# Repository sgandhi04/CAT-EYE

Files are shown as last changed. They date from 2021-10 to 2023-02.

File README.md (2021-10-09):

# CAT-EYE
New social distancing guidelines imposed during COVID-19 have made it extremely difficult for the bind to maintain their independence. The World Health Organization (WHO) estimates that 88% of the world's blind population is 50 years and older, making this demographic extremely vulnerable to COVID-19. Despite this alarming statistic, little  has been done to help the visually impaired cope with this pandemic. The CAT-EYE, a low- cost wearable assistive technology in the form of a hat, solves this problem by assisting  blind individuals with navigating in a pandemic-stricken world. The CAT-EYE consists of three systems that work together to inform a blind user about their surroundings: 1. Mask Detection: When individuals come within six-feet of the user, CAT-EYE detects their presence using a LIDAR sensor and communicates their general location through vibrotactile motors. 2. Proximity Sensing: When individuals within six feet of the user are not wearing a mask, the device beeps loudly. This system was built using computer vision for the first prototype and AI, 3. IoT, and the NVIDIA Jetson Nano for the second prototype. 3. Public Alert: The user has the option to broadcast an alert through a speaker on the hat. This alert will notify people in the user's surroundings about the presence of a blind individual. The CAT-EYE was tested by analyzing performance in the camera's field of vision from 90 to 135 degrees. Design iterations based on test results helped CAT-EYE achieve 87% accuracy. The results demonstrated the applicability of the proposed solution as a pandemic-navigation aid to the blind.

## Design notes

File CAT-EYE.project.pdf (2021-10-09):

# CAT-EYE (Covid Alert Technology)

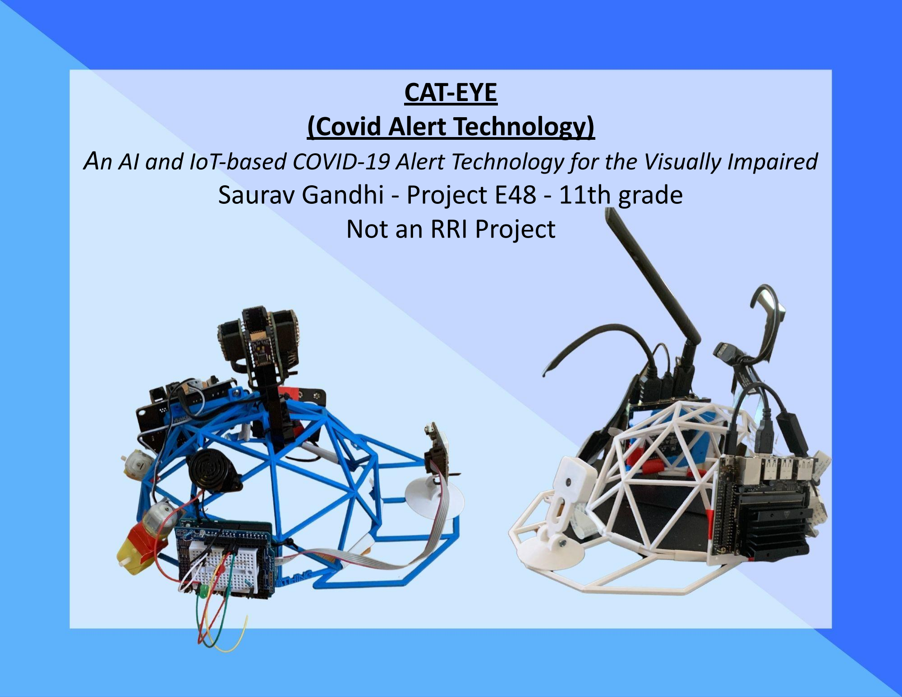
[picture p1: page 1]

## An AI and IoT-based COVID-19 Alert Technology for the Visually Impaired

# Saurav Gandhi - Project E48 - 11th grade Not an RRI Project

Introduction | Methods | Results | Discussion | Conclusion | References

Problem 1
Visually impaired people are unable to utilize typical solutions such as white cane or dogs to maintain social distances and as a result are assumed to face increased barriers in numerous domains of their lives.

Problem 2
Visually impaired people are more vulnerable to the COVID-19 infection since they cannot tell if someone in their close proximity are wearing a mask or not.

Problem 3
Social distancing guidelines published by CDC are even difficult for the normal population and it appears that the visually impaired segment of the population have been ignored as part of this solution. For visually challenged people, it is difficult to easily confirm if they are keeping the social distance with people around them.

How can the visually impaired observe social distancing guidelines while still verifying that those close to them are wearing masks, without additional dependency on people around them?

## Engineering Goal

The goal of this project is to improve mobility and quality of life of visually impaired individuals by developing an alert system that helps them maintain social distance with others and detect if those in proximity are wearing a mask.

The World Health Organization (WHO) estimates that in 2012 there were 285 million visually impaired people in the world, of which 246 million have low vision and 39 million were blind. That means 3% of the world’s population is visually impaired in some form or the other. Globally, the entire world is on edge because of COVID-19, and social distance and wearing a mask has become a new normal to prevent its spread. However, visually impaired people are finding it hard to maintain their independence in the new social distancing guidelines.

## Problem Statement

## Background Research

Research Paper - Impact of COVID-19 pandemic on people living with visual disability
Key Takeaway: Individuals living with visual impairments are more likely to be affected by COVID-19 than their peers without such impairments. This means that more than 253 million people worldwide will be at greater risk of becoming infected. An unprecedented pandemic, followed by a nationwide lockdown, is a direct threat to the people living with visual impairments and will even endanger their lives in the long run.

Online Article - Top Resources for the Blind During COVID-19 The resources listed are tips & ideas, details about peer support groups, apps, etc., for the blind and low vision community.

Online Article - Social distancing has left the visually impaired particularly isolated – it's time to reach out
Visually impaired people already experience loneliness at higher levels than the general population. Also, they're more likely to suffer from depression and have more detrimental health outcomes because of self-isolation.

Online Article - Microsoft Corporation: Custom Vision documentation
Key Takeaway: Microsoft Azure Custom Vision Website resources

Research Paper - Building Resilience against COVID-19 Pandemic Using Artificial Intelligence, Machine Learning, and IoT: A Survey of Recent Progress
Key Takeaway: Many medical sector applications such as drug delivery and infection detection based on AI and ML have been presented in this paper, and AI and ML applications for forecasting disease trends and developing social awareness programs. Also, the potential applications of wearables to track and report patients infected with COVID-19 and the recent advancements in IoT have been reviewed.
Research Paper - Color quotient based mask detection
Key Takeaway: The paper focuses on mask detection in the age of COVID – 19. The approach includes a feature extraction step, followed by a supervised learning model built with support vector machines. The ratio of color channels is taken into account to distinguish between the mask and non-mask images.

Social Media: @RNIB (Royal National Institute of Blind People): Video showing challenges faced by blind people during COVID

Social Media: #AskDontGrab
How can you best help someone with visual impairment during lockdown? #AskDontGrab, as blind Twitter users emphasize, give people distance if you think they're struggling to see you. Don't shout at people who accidentally encroach on your space. Announce who you are, and tell people when you're leaving so they don't end up speaking into thin air.

Research Paper - Remote Assistance for Blind Users in Daily Life: A Survey about Be My Eyes
Key Takeaway: The app Be My Eyes pairs blind users, with sighted volunteers for a video and audio connection. It has a large number of sighted and blind users.

Design Criteria
1. The device should be designed using CAD and manufactured with a 3D printer for maximizing adaptability and affordability.
2. Audio/Vibro-Tactile/Sensory feedback should be used to communicate information to user.
3. The device should output feedback to indicate the presence of people within six feet of proximity.
4. The device should use computer vision/AI/IoT to alert the user of maskless individuals in proximity
5. The device should have the ability to communicate to others that the user is blind.

## Design

Design Constraints
1. CAT-Eye should be a wearable (i.e. cap, necklace, fanny pack) to allow the assistive technology to “blend in” with every day apparel.
2. The scope of mask detection will be limited to the scope of the AI Image Recognition Library.
3. The range of detection is limited by the scope of the LIDAR Sensor (2 meters).
4. The range of detection is also limited to the specific computer vision camera’s range.

Subsystem Design
Based on the identified Criteria and Constraints, the following three subsystems of the CAT-Eye were identified:
| Proximity Sensing | Mask Detection | Public Alert
Objective | When individuals come within six feet of the user, CAT-EYE notifies the user of their presence and general location through vibrotactile motors. | When individuals within six feet of the user are not wearing a mask, the device beeps to warn the user. | When the user is in area with a larger population, the user can make their device emit a soft audio alert, notifying people in their immediate surroundings of their presence.
Potential Hardware Tools | LIDAR sensor, Arduino UNO, Cameras, Vibration Motors | Jeston Nano, Arduino UNO | Raspberry Pi, Arduino UNO, Speaker

Potential
Software Tools Arduino C++, Python

Azure IoT Edge,
TensorFlow, PixyMon,
Arduino C++ | Raspbian, Arduino C++

Initial Design | After conducting extensive research on different wearable devices for the visually impaired, it was decided that a cap would provide the best position for a field of vision and have the structural ability to store the three proposed subsystems ( Proximity Sensing, Mask Detection, Public Alert).

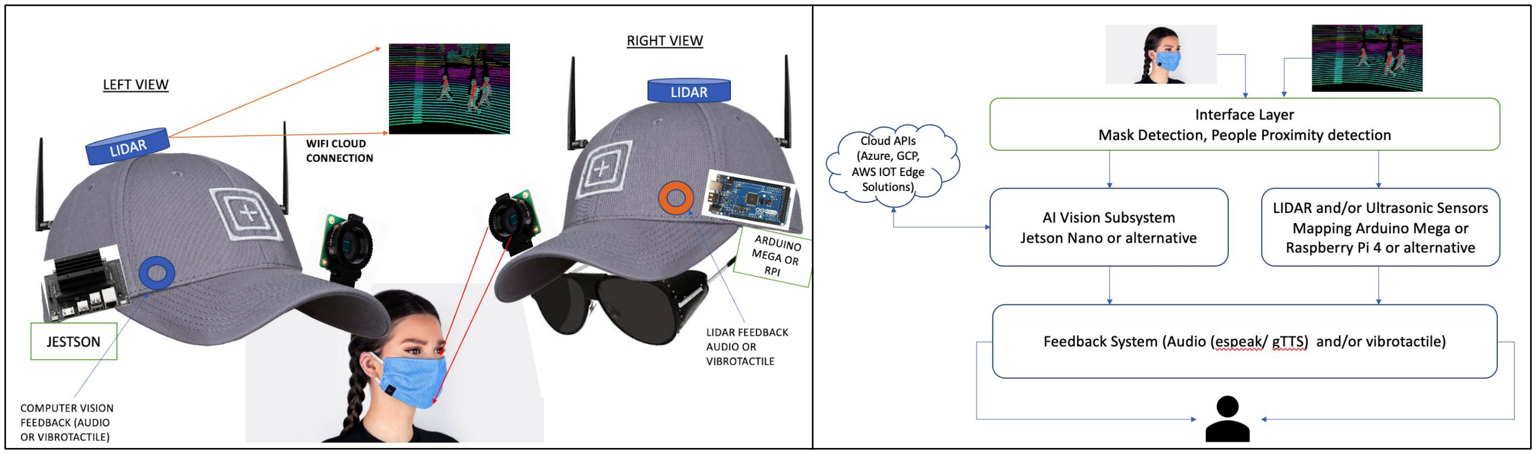
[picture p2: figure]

Initial Design System Architecture | Initial Design Logic

## Prototypes

| Proximity Sensing | Mask Detection | Comments
Prototype 1A | MappyDot Plus LIDAR + VibroTactile Motors | Pixy Cam 2 + Arduino | Pixy Cam 2 relied on the color of the masks, so only surgical masks were supported.
Prototype 1B | Same as Prototype 1 | Raspberry Pi Cam + Raspberry Pi 4 | Raspberry Pi was freezing during execution and was unable to run the model.
Prototype 2A | Same as Prototype 1 | Raspberry Pi Cam + Jetson Nano 2G with Azure Custom Vision & TensorFlow | Mask detection did not work for people behind the user. Jetson Nano 2G only had two camera ports.
Prototype 2B (In development) | Two cameras (front and back of cap) | Raspberry Pi Cam + Jetson Nano 4G with Azure Custom Vision & TensorFlow

## Build Procedure

Step 1: Design | Step 2: 3D Print
Step 3: Build | Step 4: Improve
- Design Base Chassis using CAD software (Modified from template on Thingiverse)
- Ensure that the hat is designed to fit all desired microcontrollers, components, and cameras
- 3D print designed hat using the Ender 3 3D Printer
- Mount RaspBerry Pi/Arduino/Jetson to the 3D printed hat
- Mount a camera to the front (and back if applicable)
- Secure LIDAR to the top of the hat
- Program all components using Arduino C++ and Jupyter Notebook
- Tweak parameters on mask detection/camera algorithm
- Continue to test and improve upon the recognition abilities of the device
- Refer to Prototype specs for the prototype-specific procedure

## Tools & Services Mapped to Prototype

Microcontrollers

Arduino UNO
(Prototype 1A)

Raspberry Pi 4
(Prototype 1B)

Jetson Nano 2G
(Prototype 2A)

Jetson Nano 3G
(Prototype 2B)

Cameras

Pixy Camera 2
(Prototype 1A)

Pi Camera
(Prototype 1B, 2A, 2B)

AI Tools

Azure Custom Vision,
TensorFlow, Open CV
(Prototype 1B, 2A, 2B)

Pixymon
(Prototype 1A)

Programming Tools

Arduino C++
(Prototype 1A)

Python, Jupyter
Notebook
(Prototype 1B, 2A, 2B)

This procedure outlines the process for constructing the baseline prototype hat which acted as a structure for both prototypes.

Prototype 1A Goal: Leverage Mappy Dot LIDAR, Pixy Cam 2, and Arduino UNO to build a baseline, proof-of-concept.

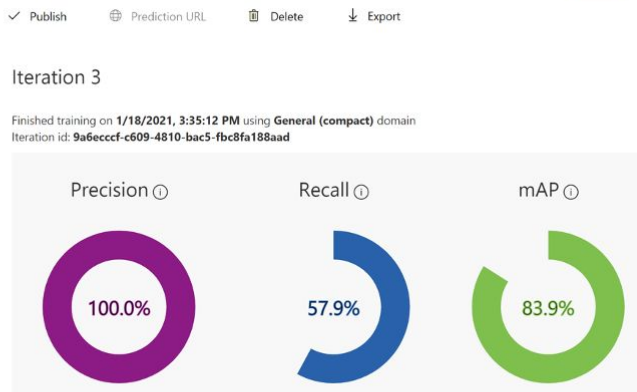
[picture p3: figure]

Mask Detection Subsystem

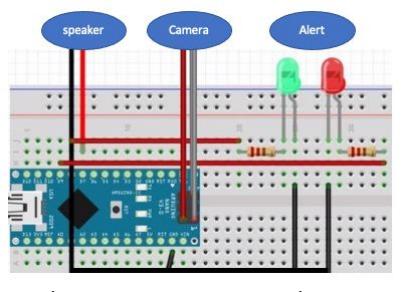
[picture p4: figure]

Proximity Sensing Subsystem

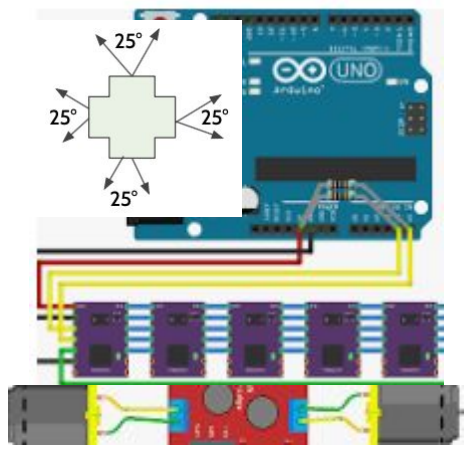
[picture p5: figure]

Learnings/Comments
This prototype had an overall 71% success rate (more details in testing section). The device functioned fairly well, however, it could only detect surgical masks.

Lidar feedback Subsystem

The Mappy Dot LIDAR uses lasers to provide distance measurements up to 2 meters in all four directions, which is a vast improvement over an ultrasonic sensor. The LIDAR drives the DC Motors connected to the Arduino to communicate the general direction of an approaching individual within 6 feet.

The cmuCam5 (Pixy Cam 2)
uses computer vision and the color of objects to create “signatures” for specific items like a mask. When a person is detected who is not wearing a mask, the device flashes red and beeps out loud.

Prototype 1B Goal: Leverage AI & IoT Tools to create a more versatile mask detection system that will go beyond surgical masks.

Mask Detection Subsystem

Proximity Sensing Subsystem
No changes were made to the proximity sensing subsystem.

Learnings/Comments
This prototype was largely unsuccessful because the Raspberry Pi was unable to run the TensorFlow Lite model due to processing power problems. Due to low functionality, testing was not conducted. As a result, another microcontroller was required to fulfill the prototype 1A goal.

In order to expand mask
detection capabilities, a
custom image recognition
model was trained using Azure Custom Vision. The model was trained three times to
maximize effectiveness and downloaded as a TensorFlow
Lite algorithm. Training model on Custom Vision AI
We were able to achieve overall accuracy of 83.9% on our data set of 85 images with 3 iterations. OpenCV was then installed on the Raspberry Pi to run the TensorFlow Algorithm. Once the algorithm was successfully installed on the Raspberry Pi, Python was used to program the audio output.

*Please note that the public alert system was not included in iteration specs due to the simplicity of the system (speaker with button)

Mask Detection System Architecture

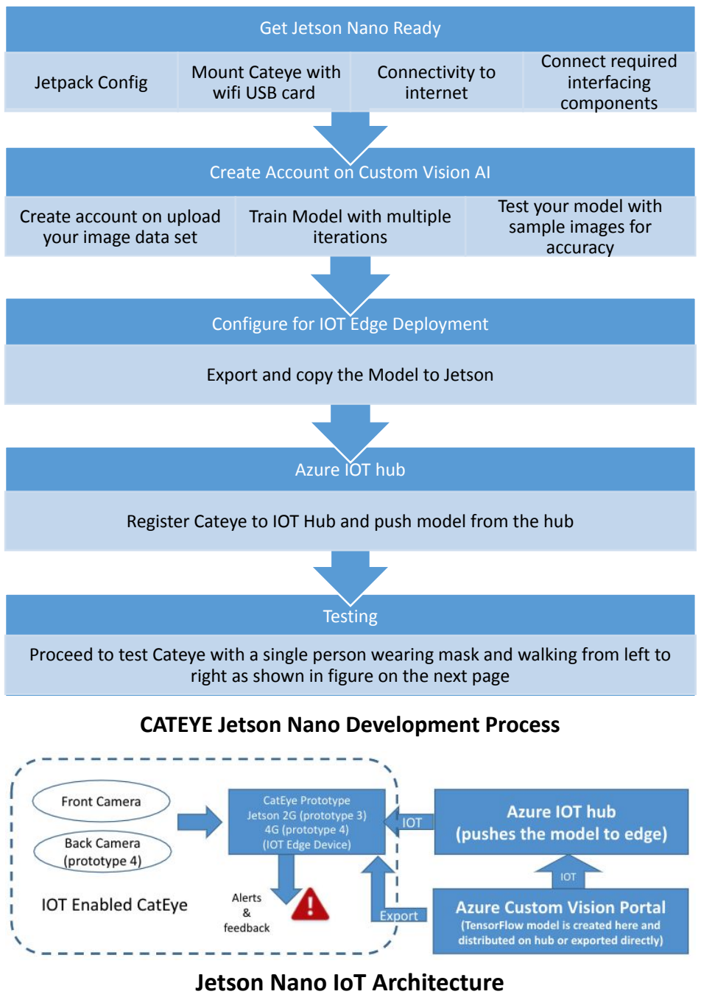
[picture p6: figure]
Testing; Azure IOT hub; Configure for IOT Edge Deployment; Export and copy the Model to Jetson; Create Account on Custom Vision AI; Create account on upload your image data set; Train Model with multiple iterations; Test your model with sample images for accuracy; Get Jetson Nano Ready; Jetpack Config; Mount Cateye with; wifi USB card; Connectivity to internet; Connect required interfacing components; CATEYE Jetson Nano Development Process; Jetson Nano IoT Architecture

Proceed to test Cateye with a single person wearing mask and walking from left to right as shown in figure on the next page

Register Cateye to IOT Hub and push model from the hub

Prototype 2A Goal: Leverage NVIDIA Jetson Nano to fulfill Prototype 1A Goal. Note: This device is referred to as Prototype 2 because a new hat was constructed to accommodate a larger board

Mask Detection Subsystem
The NVIDIA Jetson Nano was able to handle the TensorFlow model and execute the program. The NVIDIA JetPack SDK was leveraged to install and configure the algorithm. It bundles all the Jetson platform software, including TensorRT, cuDNN, CUDA Toolkit, VisionWorks, GStreamer, and OpenCV, which are built on top of L4T with LTS Linux kernel. Sample code was modified in accordance to the custom vision tensorflow model.

Proximity Sensing Subsystem
No changes were made to the proximity sensing subsystem.

Learnings/Comments
This prototype was successful and was able to detect all types of masks with an 87% success rate (more details in testing section). However, the device was unable to perform mask detection behind the user which is a necessary feature.
Prototype 2B (In Development) | Goal: To explore how the LIDAR sensors can be replaced by two cameras (one in the front, and the other in the back) which will simultaneously perform mask detection and proximity sensing.

135
°

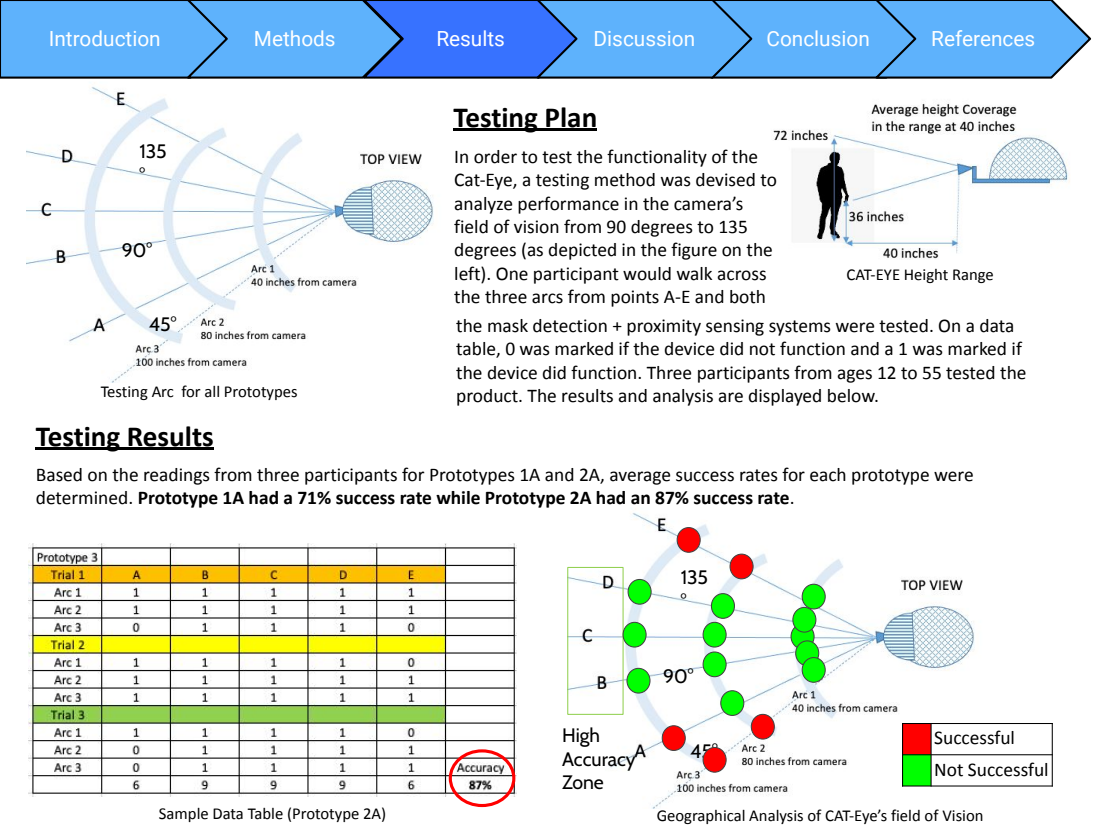
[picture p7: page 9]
Testing Plan; High Accuracy Zone

In order to test the functionality of the
Cat-Eye, a testing method was devised to
analyze performance in the camera’s
field of vision from 90 degrees to 135
degrees (as depicted in the figure on the
left). One participant would walk across
the three arcs from points A-E and both
the mask detection + proximity sensing systems were tested. On a data
table, 0 was marked if the device did not function and a 1 was marked if
the device did function. Three participants from ages 12 to 55 tested the
product. The results and analysis are displayed below.

CAT-EYE Height Range

Testing Arc for all Prototypes
Testing Results

Based on the readings from three participants for Prototypes 1A and 2A, average success rates for each prototype were
determined. Prototype 1A had a 71% success rate while Prototype 2A had an 87% success rate.

Successful
Not Successful

Sample Data Table (Prototype 2A)

Geographical Analysis of CAT-Eye’s field of Vision

Learnings from Prototype 1A

Prototype 1A did not involve IOT and had the most straightforward design. The Pixy Cam 2 served its purpose as a basic computer vision system for initial prototyping and determining the testing methodology. Although the device worked reasonably well, it was only able to detect blue surgical masks. Since masks come in all shapes and sizes, it is evident that AI needed to be integrated.

The LIDAR and vibrotactile feedback system for proximity sensing also functioned relatively well, and the hat vibrated when a person came within 2 meters of the user. However, the LIDAR sensor was found not to be very accurate beyond 1 meter.
Prototype 1B did not function well due to the limited processing power capacity fo the Raspberry Pi.

Learnings from Prototype 2A

Prototype 2A with the Jetson Nano 2 gigabyte memory developer edition was very structured as Jetson Nano ships with JetPack SDK. Jetson Nano can also function as an edge device, and Azure Custom Vision was leveraged to create a TensorFlow model for mask
detection. It is easy to export the model to Jetson Nano, and with a few configuration changes, mask detection can work efficiently. The use of IoT edge has tremendous advantages as I can potentially push another model to the same device to do a lot more than mask detection. The same device can be used as a safety helmet in any scenario. The accuracy of testing improved with Jetson Nano.

Prototype 2B
(In Development)

Prototype 2A with the 2 Gigabyte Jetson Nano was slow at times, and as a result, I contacted an NVIDIA engineer who told me to use 4 Gig Nano for better results. Since one can interface two RPI cameras to the 4Gig Nano, It made sense to use it as a final prototype. The use of the 4Gig Nano would allow for:
1. Better performance
2. Better range with front and back cameras
3. The latest Jetpack release has enhancements to help with
computer vision modules
4. The microcontroller is
certified with the Azure IoT computer vision modules
5. Ease of deployment with IoT Hub to the edge device would allow for many applications of the same hardware

71%

success rate
87%

success rate

## Data Interpretation

## Criteria/Constraint Analysis

The device was able to meet all of the criteria and constraints and achieved relative success. In addition, we were able to meet the “5 C’s of Assistive Technology Design” which was established by the Assistive Technology Lab at Stanford University!:
1. Comfort - form fitting,flexible, hands free wearable
2. Cosmesis - Doesn’t change the appearance of the user significantly
3. Function - With a success rate of 87%, it has high reliability in terms of its function
4. Cost - Costs less than $300, making it more economically accessible than other assistive device
5. Cool - The chassis can be customized to various shapes, colors and prints.

## Use Cases and Applications

The prototype solution can have many use cases beyond Covid mask detection and alert for the visually impaired. With the right trained tensorflow export from IOT hub, one can use the same device in various scenarios like:
- Law enforcement and security personnel at the airports, hospitals, offices etc to monitor people who are not conforming to social distancing and masks guidelines.
- Construction site workers, bikers, soldiers, public safety officers can all us a customized version of CAT-EYE to meet their specific needs, specially since the helmet is capable of transmitting data based on IoT, that can be leveraged to significantly increase safety.

## Novelty of Solution

While much work has been done to develop an effective and reliable way to monitor social distancing, little has been done to discover how it can be used for IoT-based assistive technologies for the visually impaired, which is what makes CAT- EYE unique. By far, the visually impaired population has been neglected during this pandemic, but this device attempts to restore their mobility back to pre-pandemic levels.

## Project Video Link:

# https://youtu.be/TZ02UoSkc_I

## Future Prospects

Future steps will be taken by me to improve the efficiency and accuracy of the device. Below are a few examples of further research:
1. Utilizing a more powerful Jetson Nano would allow the CAT-eye to connect to multiple cameras and replace the need for a LIDAR sensor
2. Exploring other forms of human-device interaction such as audio output.
3. Exploring if this device can be solar powered
4. Exploring how this device can retrofitted to other wearables or be applied to a different disability demographic

## References

1. “Azure Machine Learning - ML as a Service: Microsoft Azure.” ML as a Service | Microsoft Azure,
azure.microsoft.com/en-us/services/machine-learning/.
2. Dusty-Nv. “Dusty-Nv/Jetson-Inference.” GitHub, github.com/dusty-nv/jetson-inference.
3. Hui, Jonathan. “Real-Time Object Detection with YOLO, YOLOv2 and Now YOLOv3.” Medium, Medium, 27 Aug. 2019, medium.com/@jonathan_hui/real-time-object-detection-with-yolo-yolov2-28b1b93e2088.
4. “Intel® Distribution of OpenVINO™ Toolkit.” Intel, software.intel.com/en-us/openvino-toolkit/deep-learning-cv.
5. “Jetson Nano Developer Kit.” NVIDIA Developer, 28 Jan. 2021, developer.nvidia.com/embedded/jetson-nano-developer-kit.
6. Senjam, Suraj S. "Impact of COVID-19 pandemic on people living with visual disability." Indian journal of ophthalmology 68.7 (2020): 1367.
7. Abir, S. M., et al. "Building Resilience against COVID-19 Pandemic Using Artificial Intelligence, Machine Learning, and IoT: A Survey of Recent Progress." IoT 1.2 (2020): 506-528.
8. I. Buciu, "Color quotient based mask detection," 2020 International Symposium on Electronics and Telecommunications (ISETC), Timisoara, Romania, 2020, pp. 1-4, doi: 10.1109/ISETC50328.2020.9301079.
9. Avila, Mauro, et al. "Remote assistance for blind users in daily life: A survey about be my eyes." Proceedings of the 9th ACM International Conference on PErvasive Technologies Related to Assistive Environments. 2016.
10. AdaptiVision. “Top Resources for the Blind during COVID-19.” AdaptiVision, 7 Apr. 2020, lowvisionsource.com/top-resources-for-the-blind-during-covid-19/. Accessed 5 Mar. 2021.
11. Wilkinson, Meredith. “Social Distancing Has Left the Visually Impaired Particularly Isolated – It’s Time to Reach Out.” World Economic Forum, 12 Aug. 2020, www.weforum.org/agenda/2020/08/covid19-pandemic-visually-impaired-independence/.
12. Microsoft. “Custom Vision Documentation - Quickstarts, Tutorials, API Reference - Azure Cognitive Services.” Docs.microsoft.com, docs.microsoft.com/en-us/azure/cognitive-services/custom-vision-service/. Accessed 5 Mar. 2021.
13. Davis, Alicia J., Brian M. Kelly, and Mary Catherine Spires. Prosthetic restoration and rehabilitation of the upper and lower extremity. Demos Medical Publishing, 2013.

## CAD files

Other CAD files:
sg-rpicam-base.3mf
sg-hat-rim.3mf
sg-cap.3mf

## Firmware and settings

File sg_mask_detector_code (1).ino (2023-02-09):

//include librarys
#include <Pixy2.h>
//create pixy object
Pixy2 pixy;
//define led pins
int led1 = 9;
int led2 = 8;
//setup code
void setup()
{
  //setup leds
  pinMode(led1, OUTPUT);
  pinMode(led2, OUTPUT);
  //initilize pixy2
  pixy.init();
}
//loop code
void loop()
{ 
  //grab data from pixy
  pixy.ccc.getBlocks();
  //if mask is detected...
  if (pixy.ccc.numBlocks)
  {
    //turn off red led
    digitalWrite(led1, LOW);
    //turn on green led
    digitalWrite(led2, HIGH);
    //turn off buzzer
    noTone(7); 
    delay(1000);
  }
  //else...
  else {
    //turn on red led
    digitalWrite(led1, HIGH);
    //turn off green led
    digitalWrite(led2, LOW);
    //turn on buzzer
    tone(7, 261);
    delay(1000);
  }
}
